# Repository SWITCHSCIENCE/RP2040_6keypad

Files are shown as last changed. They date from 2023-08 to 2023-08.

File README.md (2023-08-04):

# RP2040_6keypad

This repository contains KiCad data for 6keypads using the Switch Science RP2040 breakout board.

[Picossci RP2040 ピッチ変換基板](https://ssci.to/8440)を利用したKiCadサンプルデータのリポジトリです。

## KiCad_Project

KiCadプロジェクトです。回路図PDFを含みます。

## RP2040_breakout_KiCad_Symbol

[Picossci RP2040 ピッチ変換基板](https://ssci.to/8440)のKiCad用回路図シンボルとフットプリントデータです。この基板の販売ページで配布されている物と同じです。

## sample_software/rp2040_6key_pad_example

Raspberry Pi Pico C/C++ SDKを用いた簡単なサンプルソフトウェアです。USBシリアル変換アダプターとして機能し、押されたキーの番号をPCのシリアルポートへ送信します。
さらに押されたキーに対応するLEDが点灯します。簡単なREADME.mdを添付しています。

## qmk_firmware/qmk_configs_for_rp2040_6_keypad

QMK Firmwareをrp2040 6-key padに対応させるための設定ファイルとソースコードを書きました。ソースコード差分のみzipファイルにしています。
ビルド方法などの詳細は中のREADME.mdをご確認ください。
今回は6つのキーをBackspace、Enter、上下左右キーに割り振っています。LEDはCapsLockのLEDインジケーターとして動作します。

## prk_firmware/keymap.rb

PRK Firmware用のキーボード設定ファイルです。[PRK Firmware](https://github.com/picoruby/prk_firmware)のuf2ファイルを書き込み後、このファイルkeymap.rbをコピーしてください。キーマップや挙動を変更する時はこのkeymap.rbを書き換えるだけでいいのでQMK Firmwareに比べて試行が簡単です。
6つのキーには123456の数字を割り当ててあり、14、25、36のキーそれぞれを押すと対応したLEDが光ります。

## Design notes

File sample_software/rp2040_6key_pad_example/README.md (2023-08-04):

# rp2040_6key_pad_example

## 動作
- USBシリアル変換アダプタとして機能し、PCのシリアルポートへ押されたキーの番号を文字列で送信します
- 例えばSW1を押したら"Button0 Pressed"がPCへ送信されます
- 押されたキーに応じて、LEDを点灯させます

## ビルド方法
rapsberrypi pico sdkが必要ですので下記URLに従ってインストールしてください。

https://github.com/raspberrypi/pico-sdk

インストールが完了したら、下記コマンドで.uf2ファイルが生成されます。
```
mkdir build
cd build
cmake .. -DPICO_SDK_PATH=<raspberrypi picoのSDKが保存されいるディレクトリを指定する>
make
```

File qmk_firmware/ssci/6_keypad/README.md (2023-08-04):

# qmk confings for RP2040 6-key pad

このソースコードはRP2040 6-Key Padをqmkに対応させるためのものです。

## 動作
### キーマッピング

デフォルトのキーマッピングは下記の通りです。`ssci/6_keypad/keymaps/default/keymap.c`を編集することで任意のキーマッピングを設定することができます。

左上のボタンがボタン1です。右下へ向けてボタン2,ボタン3と続きます。

- ボタン1 Backspaceキー
- ボタン2 上キー
- ボタン3 Enterキー
- ボタン4 左キー
- ボタン5 下キー
- ボタン6 右キー

### LED

LEDは左からNumLock, CapsLock, ScrollLockのインジケータLEDになっています。

## ビルド方法

下記URLのqmkのマニュアルに従ってqmkの開発環境をセットアップします。

https://docs.qmk.fm/#/newbs_getting_started

「3. Run QMK Setup」では`qmk setup -H <path>`コマンドを使ってqmkのディレクトリを指定すると今後の作業が楽になります。

「4. Test Your Build Environment」まで進めてビルドが成功することを確認します。

ssciディレクトリをqmkのソースコードのkeyboardsディレクトリ内にコピーします。

下記コマンドでコンパイルします。
```
qmk compile -kb ssci/6_keypad -km default
```
コンパイルが成功するとqmkソースコードのディレクトリに`ssci_6_keypad_default.uf2`が生成されます。

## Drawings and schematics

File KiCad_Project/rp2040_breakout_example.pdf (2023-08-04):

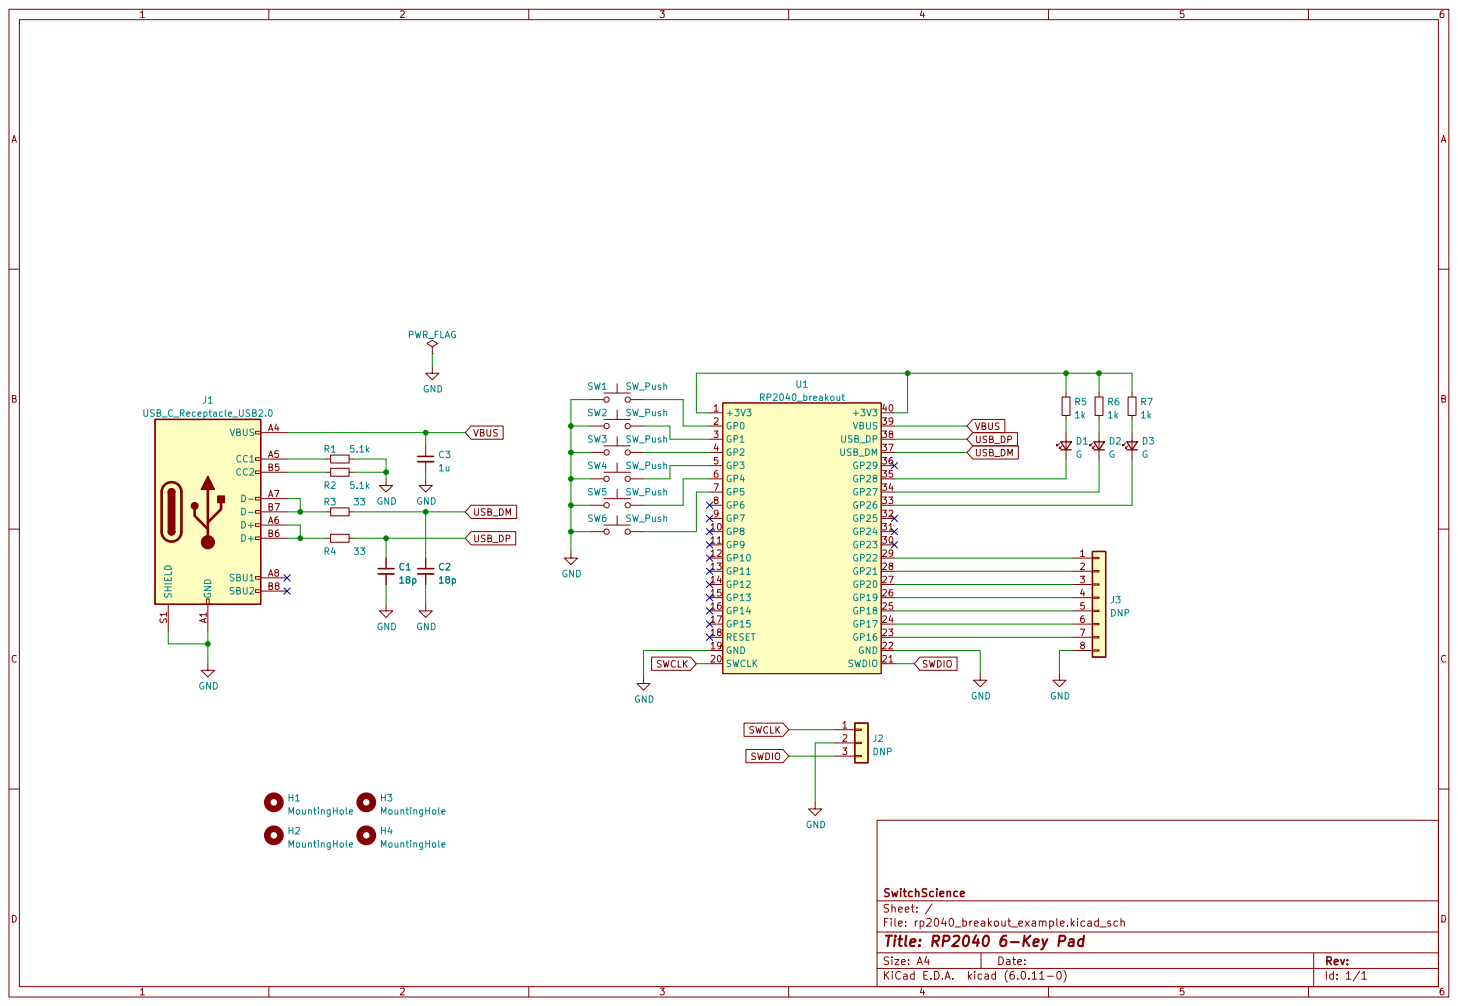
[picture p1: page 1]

Id: 1/1 Title: RP2040 6-Key Pad

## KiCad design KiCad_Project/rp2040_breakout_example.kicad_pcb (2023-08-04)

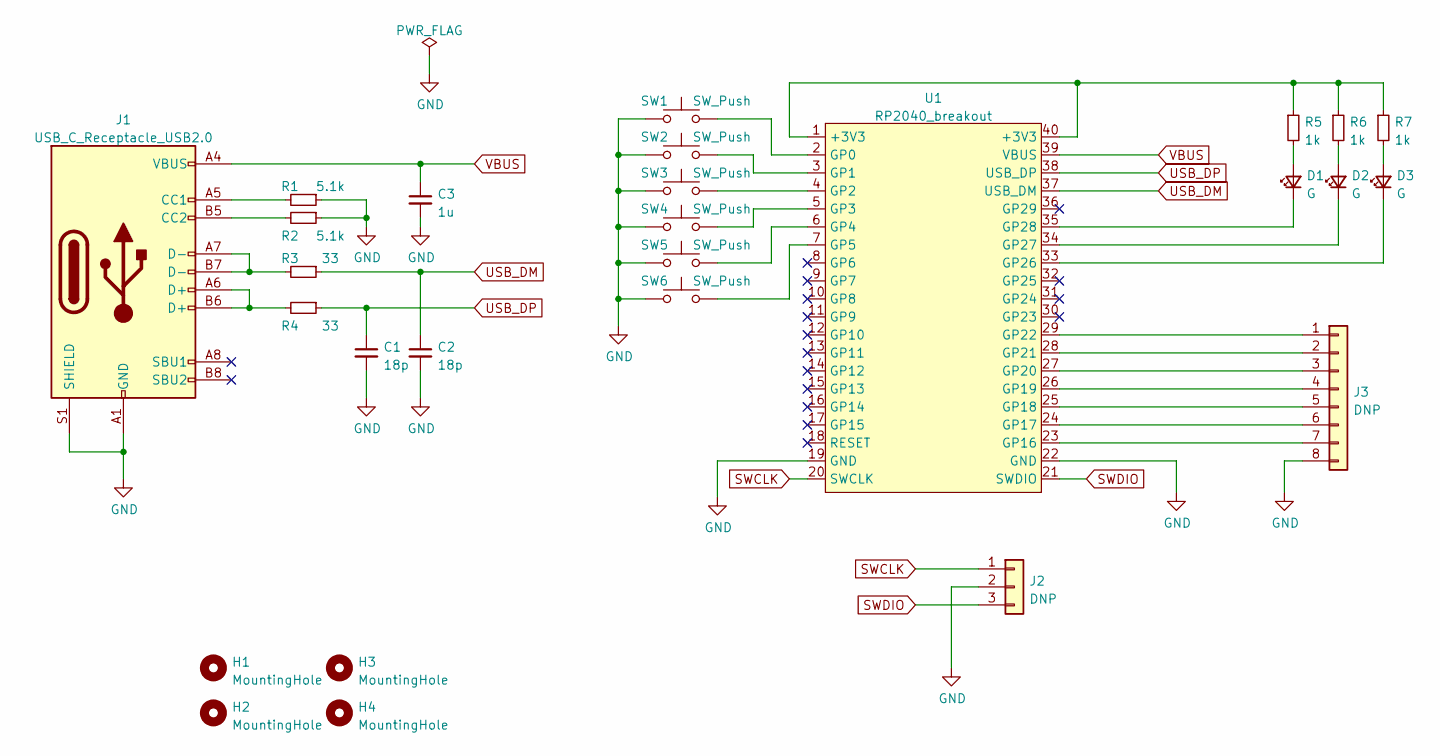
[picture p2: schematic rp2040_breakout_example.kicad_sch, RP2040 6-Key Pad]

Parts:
C1, C2: 18p; C_0402_1005Metric
C3: 1u; C_0603_1608Metric
D1, D2, D3: G; LED_0603_1608Metric
H1, H2, H3, H4: MountingHole; MountingHole_3.2mm_M3
J1: USB_C_Receptacle_USB2.0; USB_C_Receptacle_XKB_U262-16XN-4BVC11
J2: DNP; PinHeader_1x03_P2.54mm_Vertical
J3: DNP; PinHeader_1x08_P2.54mm_Vertical
R1, R2: 5.1k; R_0402_1005Metric
R3, R4: 33; R_0402_1005Metric
R5, R6, R7: 1k; R_0402_1005Metric
SW1, SW2, SW3, SW4, SW5, SW6: SW_Push; SW_Cherry_MX_1.00u_PCB
U1: RP2040_breakout; RP2040_Breakout

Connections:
GND: C1.2, C2.2, C3.2, J1.A1 (GND), J1.A12 (GND), J1.B1 (GND), J1.B12 (GND), J1.S1 (SHIELD), J2.2, J3.8, R1.1, R2.1, SW1.1, SW2.1, SW3.1, SW4.1, SW5.1, SW6.1, U1.19 (GND), U1.22 (GND)
unnamed: D1.1 (K), U1.35 (GP28)
unnamed: D1.2 (A), R5.2
unnamed: D2.1 (K), U1.34 (GP27)
unnamed: D2.2 (A), R6.2
unnamed: D3.1 (K), U1.33 (GP26)
unnamed: D3.2 (A), R7.2
unnamed: J1.A5 (CC1), R1.2
unnamed: J1.A6 (D+), J1.B6 (D+), R4.2
unnamed: J1.A7 (D-), J1.B7 (D-), R3.2
unnamed: J1.B5 (CC2), R2.2
unnamed: J3.1, U1.29 (GP22)
unnamed: J3.2, U1.28 (GP21)
unnamed: J3.3, U1.27 (GP20)
unnamed: J3.4, U1.26 (GP19)
unnamed: J3.5, U1.25 (GP18)
unnamed: J3.6, U1.24 (GP17)
unnamed: J3.7, U1.23 (GP16)
unnamed: R5.1, R6.1, R7.1, U1.1 (+3V3), U1.40 (+3V3)
unnamed: SW1.2, U1.2 (GP0)
unnamed: SW2.2, U1.3 (GP1)
unnamed: SW3.2, U1.4 (GP2)
unnamed: SW4.2, U1.5 (GP3)
unnamed: SW5.2, U1.6 (GP4)
unnamed: SW6.2, U1.7 (GP5)
SWCLK: J2.1, U1.20 (SWCLK)
SWDIO: J2.3, U1.21 (SWDIO)
USB_DM: C2.1, R3.1, U1.37 (USB_DM)
USB_DP: C1.1, R4.1, U1.38 (USB_DP)
VBUS: C3.1, J1.A4 (VBUS), J1.A9 (VBUS), J1.B4 (VBUS), J1.B9 (VBUS), U1.39 (VBUS)

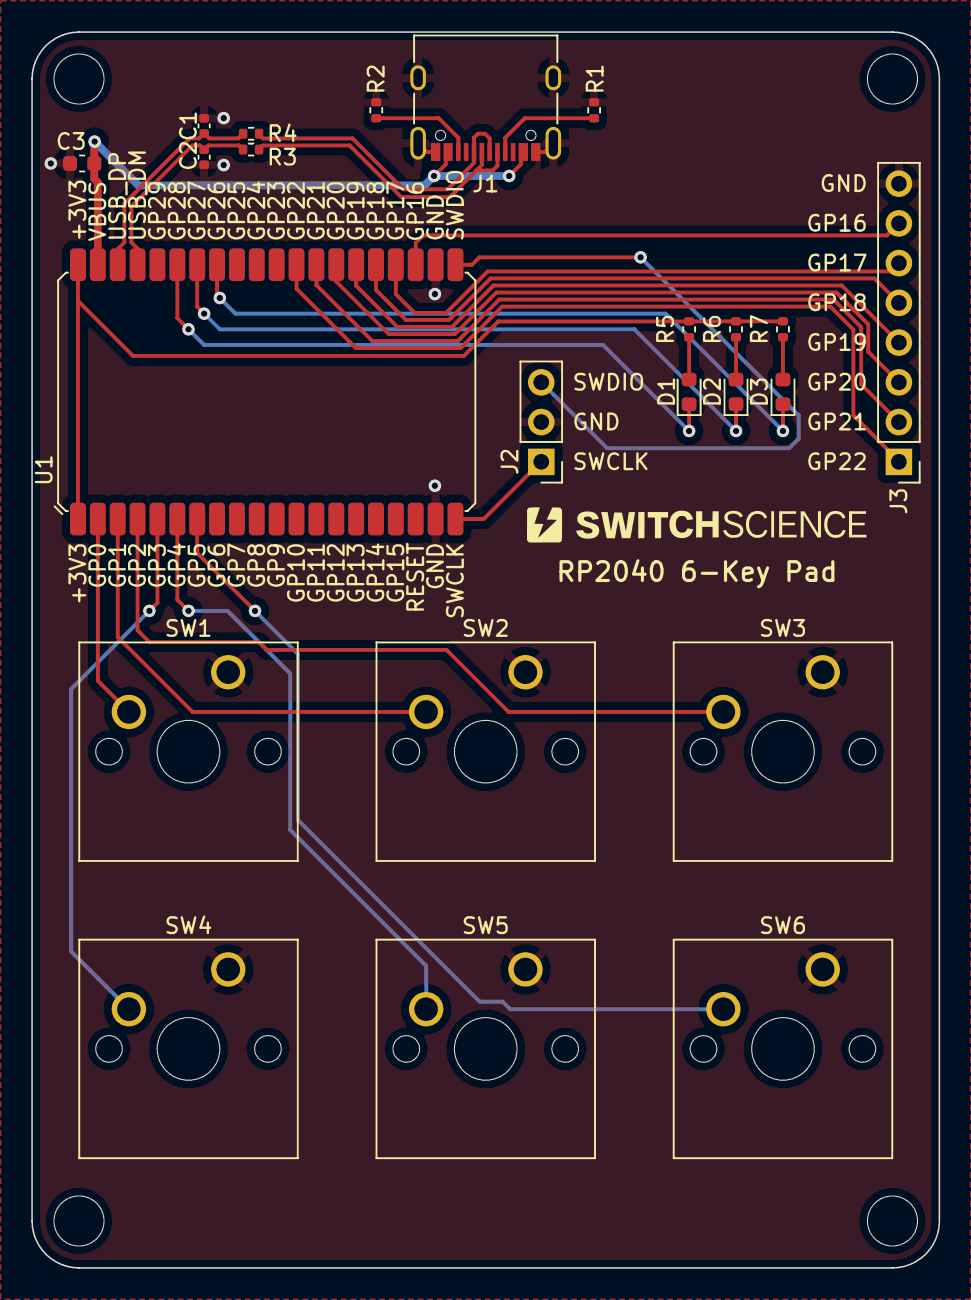
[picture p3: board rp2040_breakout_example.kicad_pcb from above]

Board: 2 copper layers, 58.0 x 79.0 mm, 27 parts (0 on the bottom side), 30 nets.

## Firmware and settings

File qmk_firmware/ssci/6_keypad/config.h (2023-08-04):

// Copyright (c) 2023 Switch Science, Inc.
// SPDX-License-Identifier: GPL-2.0-or-later

#pragma once

/*
 * Feature disable options
 *  These options are also useful to firmware size reduction.
 */

/* disable debug print */
//#define NO_DEBUG

/* disable print */
//#define NO_PRINT

/* disable action features */
//#define NO_ACTION_LAYER
//#define NO_ACTION_TAPPING
//#define NO_ACTION_ONESHOT

#define LED_NUM_LOCK_PIN GP28
#define LED_CAPS_LOCK_PIN GP27
#define LED_SCROLL_LOCK_PIN GP26
#define LED_PIN_ON_STATE 0

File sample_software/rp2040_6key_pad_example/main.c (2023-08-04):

/**
 * Copyright (c) 2023 Switch Science, Inc.
 *
 * SPDX-License-Identifier: BSD-3-Clause
 */

#include <stdio.h>
#include "pico/stdlib.h"

#define BUTTON_GPIO 0
#define BUTTON_GPIO1 1
#define BUTTON_GPIO2 2
#define BUTTON_GPIO3 3
#define BUTTON_GPIO4 4
#define BUTTON_GPIO5 5

#define LED0 25
#define LED1 28
#define LED2 27
#define LED3 26

int main() {
    stdio_init_all();

    gpio_init(BUTTON_GPIO);
    gpio_set_dir(BUTTON_GPIO, GPIO_IN);
    gpio_pull_up(BUTTON_GPIO);
    gpio_set_input_hysteresis_enabled(BUTTON_GPIO, 1);

    gpio_init(BUTTON_GPIO1);
    gpio_set_dir(BUTTON_GPIO1, GPIO_IN);
    gpio_pull_up(BUTTON_GPIO1);
    gpio_set_input_hysteresis_enabled(BUTTON_GPIO1, 1);

    gpio_init(BUTTON_GPIO2);
    gpio_set_dir(BUTTON_GPIO2, GPIO_IN);
    gpio_pull_up(BUTTON_GPIO2);
    gpio_set_input_hysteresis_enabled(BUTTON_GPIO2, 1);

    gpio_init(BUTTON_GPIO3);
    gpio_set_dir(BUTTON_GPIO3, GPIO_IN);
    gpio_pull_up(BUTTON_GPIO3);
    gpio_set_input_hysteresis_enabled(BUTTON_GPIO3, 1);

    gpio_init(BUTTON_GPIO4);
    gpio_set_dir(BUTTON_GPIO4, GPIO_IN);
    gpio_pull_up(BUTTON_GPIO4);
    gpio_set_input_hysteresis_enabled(BUTTON_GPIO4, 1);

    gpio_init(BUTTON_GPIO5);
    gpio_set_dir(BUTTON_GPIO5, GPIO_IN);
    gpio_pull_up(BUTTON_GPIO5);
    gpio_set_input_hysteresis_enabled(BUTTON_GPIO5, 1);

    gpio_init(LED0);
    gpio_set_dir(LED0, GPIO_OUT);
    gpio_disable_pulls(LED0);
    gpio_put(LED0, 0);

    gpio_init(LED1);
    gpio_set_dir(LED1, GPIO_OUT);
    gpio_disable_pulls(LED1);
    gpio_put(LED1, 1);

    gpio_init(LED2);
    gpio_set_dir(LED2, GPIO_OUT);
    gpio_disable_pulls(LED2);
    gpio_put(LED2, 1);

    gpio_init(LED3);
    gpio_set_dir(LED3, GPIO_OUT);
    gpio_disable_pulls(LED3);
    gpio_put(LED3, 1);

    uint8_t btn0 = 0;
    uint8_t btn1 = 0;
    uint8_t btn2 = 0;
    uint8_t btn3 = 0;
    uint8_t btn4 = 0;
    uint8_t btn5 = 0;

    uint8_t btn0_prev = 0;
    uint8_t btn1_prev = 0;
    uint8_t btn2_prev = 0;
    uint8_t btn3_prev = 0;
    uint8_t btn4_prev = 0;
    uint8_t btn5_prev = 0;

    while (true) {
        btn0 = !gpio_get(BUTTON_GPIO);
        btn1 = !gpio_get(BUTTON_GPIO1);
        btn2 = !gpio_get(BUTTON_GPIO2);
        btn3 = !gpio_get(BUTTON_GPIO3);
        btn4 = !gpio_get(BUTTON_GPIO4);
        btn5 = !gpio_get(BUTTON_GPIO5);

        gpio_put(LED1, !(btn0 | btn3));
        gpio_put(LED2, !(btn1 | btn4));
        gpio_put(LED3, !(btn2 | btn5));

        if((btn0 == 1) && (btn0_prev == 0)){
            printf("Button0 Pressed\n");
        }
        if ((btn1 == 1) && (btn1_prev == 0)) {
            printf("Button1 Pressed\n");
        }
        if ((btn2 == 1) && (btn2_prev == 0)) {
            printf("Button2 Pressed\n");
        }
        if ((btn3 == 1) && (btn3_prev == 0)) {
            printf("Button3 Pressed\n");
        }
        if ((btn4 == 1) && (btn4_prev == 0)) {
            printf("Button4 Pressed\n");
        }
        if ((btn5 == 1) && (btn5_prev == 0)) {
            printf("Button5 Pressed\n");
        }

        btn0_prev = btn0;
        btn1_prev = btn1;
        btn2_prev = btn2;
        btn3_prev = btn3;
        btn4_prev = btn4;
        btn5_prev = btn5;

        sleep_ms(1);

    }
    return 0;
}

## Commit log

2023-08-04 Add KiCad symbol.
2025-07-17 Update keymap.rb
    rpk firmware 0.10.0に対応
